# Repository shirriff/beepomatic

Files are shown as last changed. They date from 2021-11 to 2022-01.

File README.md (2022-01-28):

# beepomatic: automated backplane finding for Apollo-era hardware

This repository describes hardware and software for reverse-engineering a test box used with Apollo space hardware.
This is unlike to be useful to anyone else, but I figure I'll document it.

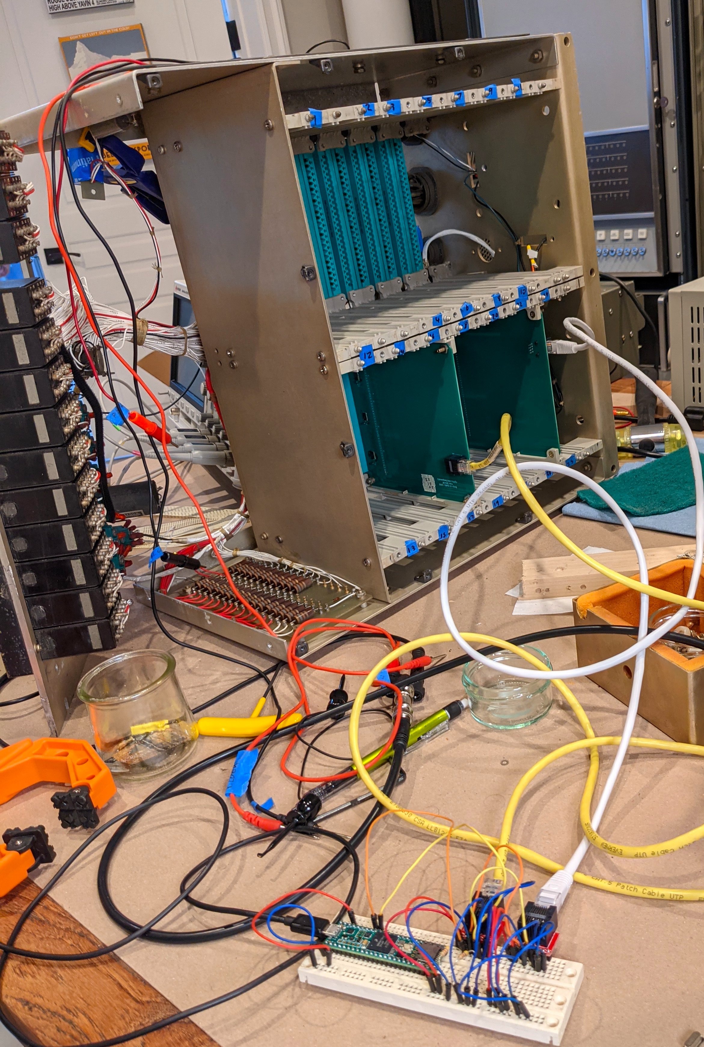
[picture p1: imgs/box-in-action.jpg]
The test system in action. Two boards are plugged into the box at the back and are controlled by the breadboarded Teensy in front.


## Background

In the Apollo mission to the Moon, the [Up-Data Link](https://mobile.twitter.com/kenshirriff/status/1433169432709373953) was used to send data up to the spacecraft from
the ground.

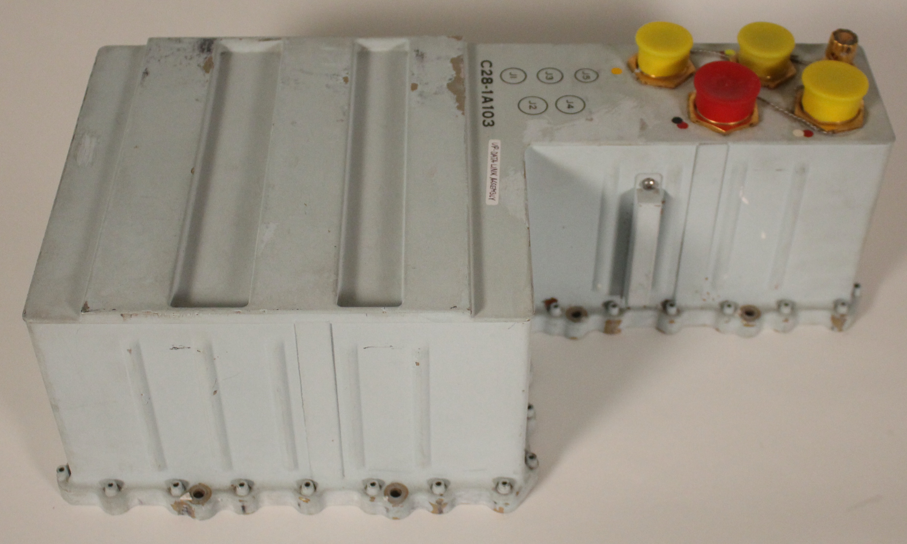
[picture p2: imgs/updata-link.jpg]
The Up-Data Link is a metal box painted a military gray. The box is roughly L-shaped and has several round connectors on top.


To test the Up-Data Link, the [Up-Data Link Confidence Test Set](https://twitter.com/kenshirriff/status/1432411774985195527) was used.
Unfortunately, we can't find any documentation on this test box, so I'm reverse-engineering it.

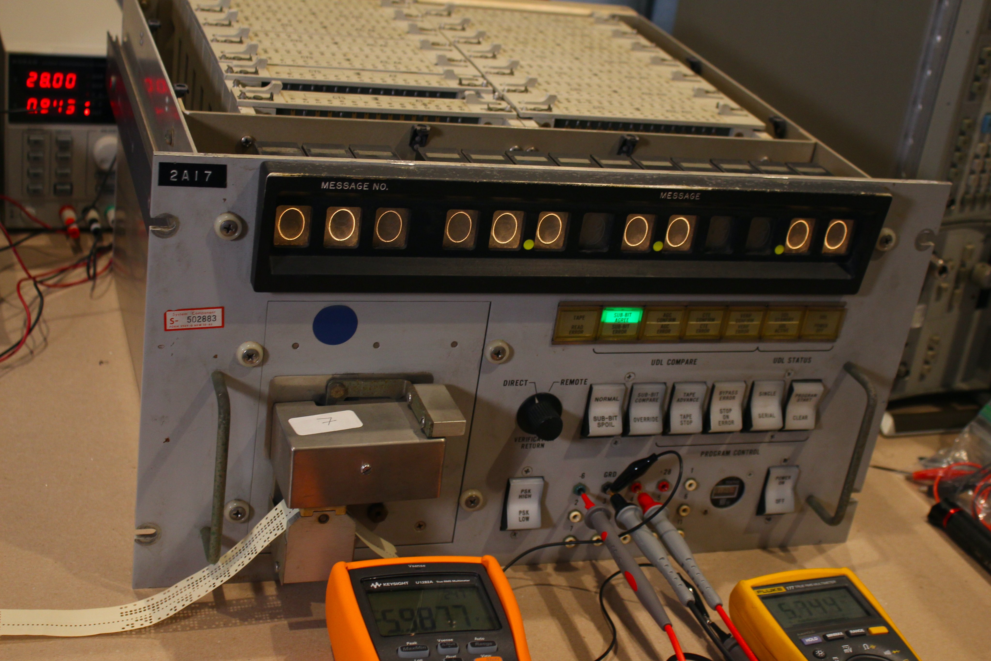
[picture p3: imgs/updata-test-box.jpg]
The up-data test box is a large rack-mountable box. It has a paper tape reader and switches, buttons, and illuminated digits on the front. 25 modules are plugged into the top of the box.


The box consists of 25 circuit boards plugged into a wire-wrapped backplane. It's almost impossible to figure out how the boards are connected through this
tangle of wires. I beeped out some connections with a multimeter, but it is extremely tedious to do this manually through trial and error.
So I decided to automate the beeping process.

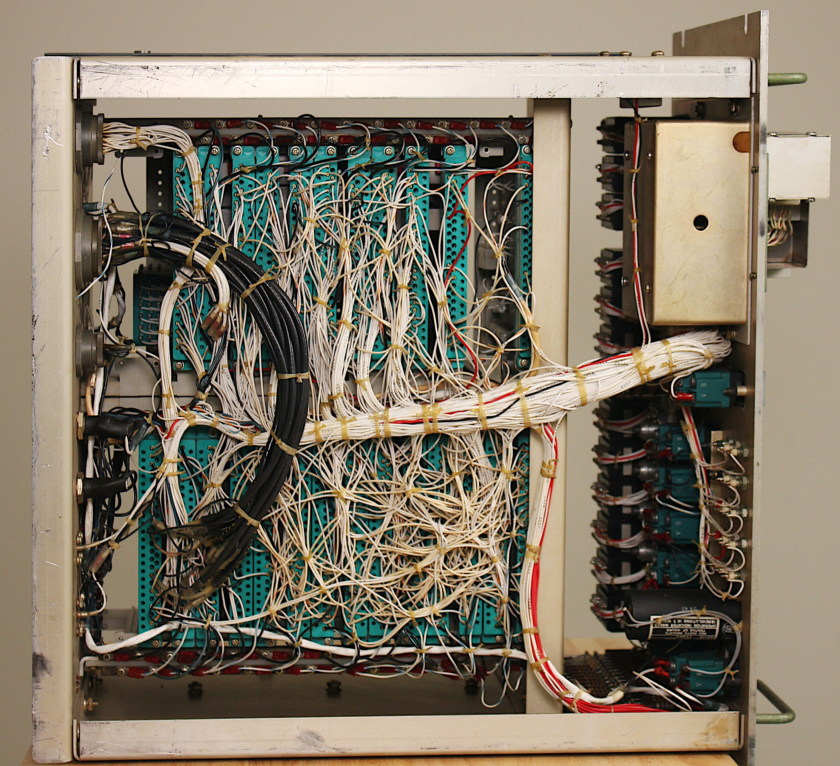
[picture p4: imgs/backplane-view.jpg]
View of the backplane, a tangled mass of white wires.


## Beep-o-matic

My idea was to build two boards that will automatically beep out the connections between them.
The idea is to pull one pin low and then see which other pins are pulled low on the other board; this indicates the pins are connected.

I still need to put boards into each combination of slots, so I need to run 300 scans. This is still somewhat tedious, but much better than probing the entire backplane
manually to find a single connection.

### Implementation

The backplane is implemented with 47-pin Elco connectors. Each board has three 16-bit GPIO chips connected to these pins; I used [PCA9555A](https://www.nxp.com/docs/en/data-sheet/PCA9555A.pdf) chips.)
The chips are driven over I2C from a Teensy microcontroller.
(Thanks to [PCBWay](https://www.pcbway.com/) for sponsoring these boards.)

On the software side, I wrote a simple program *beeper.ino*, which cycles through the 47 pins on each board, pulling each pin low in turn. It reads the remaining pins to see which ones are low
and outputs that data to the serial port. It takes under a second to perform this scan.

I run *beeper.py* on my laptop; it records the output for each scan in output files.

Finally, the program *net.py* processes these output files to find connected components and output the wiring nets.

### Issues

I pulled out all the boards, so I don't get any interference from the circuitry. However, the power and ground connections are still wired to the filter capacitors.
As a result, I see phantom connections between power and ground because of current flow through the capacitor. (This happens with multimeter beeping too.)
More inconvenient, though, is that once the capacitors are charged low, they can continue to pull the ground pins low even when I'm scanning unrelated pins.
This can make it appear that most pins are connected to ground. I filter this out in the software analysis.

A second problem is that the box has a lot of wiring to front panel switches, which are connected to power or ground (depending on their position).
I'll need to sort out that wiring manually.

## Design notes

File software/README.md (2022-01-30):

# Software for use with beepomatic

Disclaimer: these are ad hoc scripts that I used once, so don't expect them to be generally usefl.

The main programs:

* beeper.ino: This runs on the Teensy and drives the boards, scanning all pin pairs. It returns raw connectivity data over the serial port.

* beeper.py: Driver for beeper.ino. Run this on your laptop and it talks to the Teensy over the serial port. The workflow is that you plug the boards into two slots. Then enter the slot numbers into beeper.py. It will record the results in a file output-*n*, creating a new file each time you run it. So you end up with one or more output-*n* files with the data.

* net.py: Makes a net from the output-*n* files, determining the connected components. If a `labels.txt` file exists, it will label pins from that file.
Output to stdout, can be directed to out.txt.

Other programs:

* raw.ino: Runs on the Teensy to detect raw connections. Instead of scanning, this program just returns raw data. The idea is that you can probe pins manually and this program will let you know what the pin is connected to.

* changes.py: Driver program that uses audio to indicate any connectivity changes. If you're poking around in the box flipping switches and can't watch the screen, this program lets you know when something happens.

* fixlabels.py: The idea is to list all the unconnected pins in missing-pins.txt. This program then scans labels.txt and missing-pins.txt to make sure they are consistent, pins are either labeled or explicitly marked as missing.
This program generates labels-new.txt, the updated version.

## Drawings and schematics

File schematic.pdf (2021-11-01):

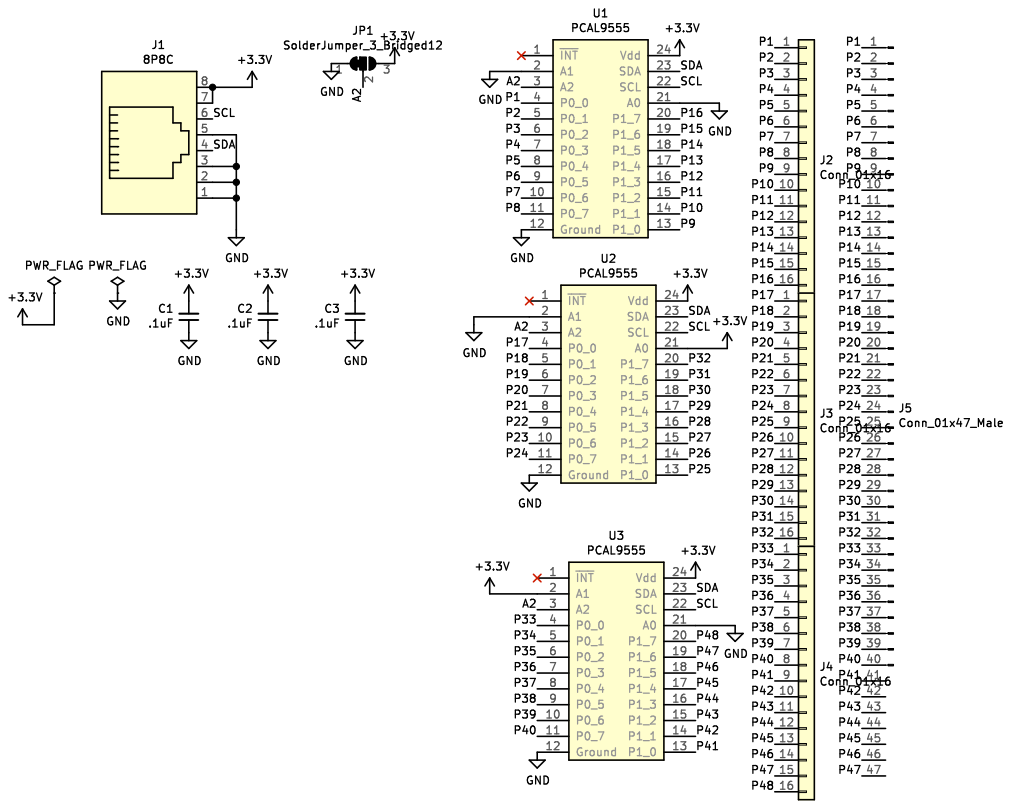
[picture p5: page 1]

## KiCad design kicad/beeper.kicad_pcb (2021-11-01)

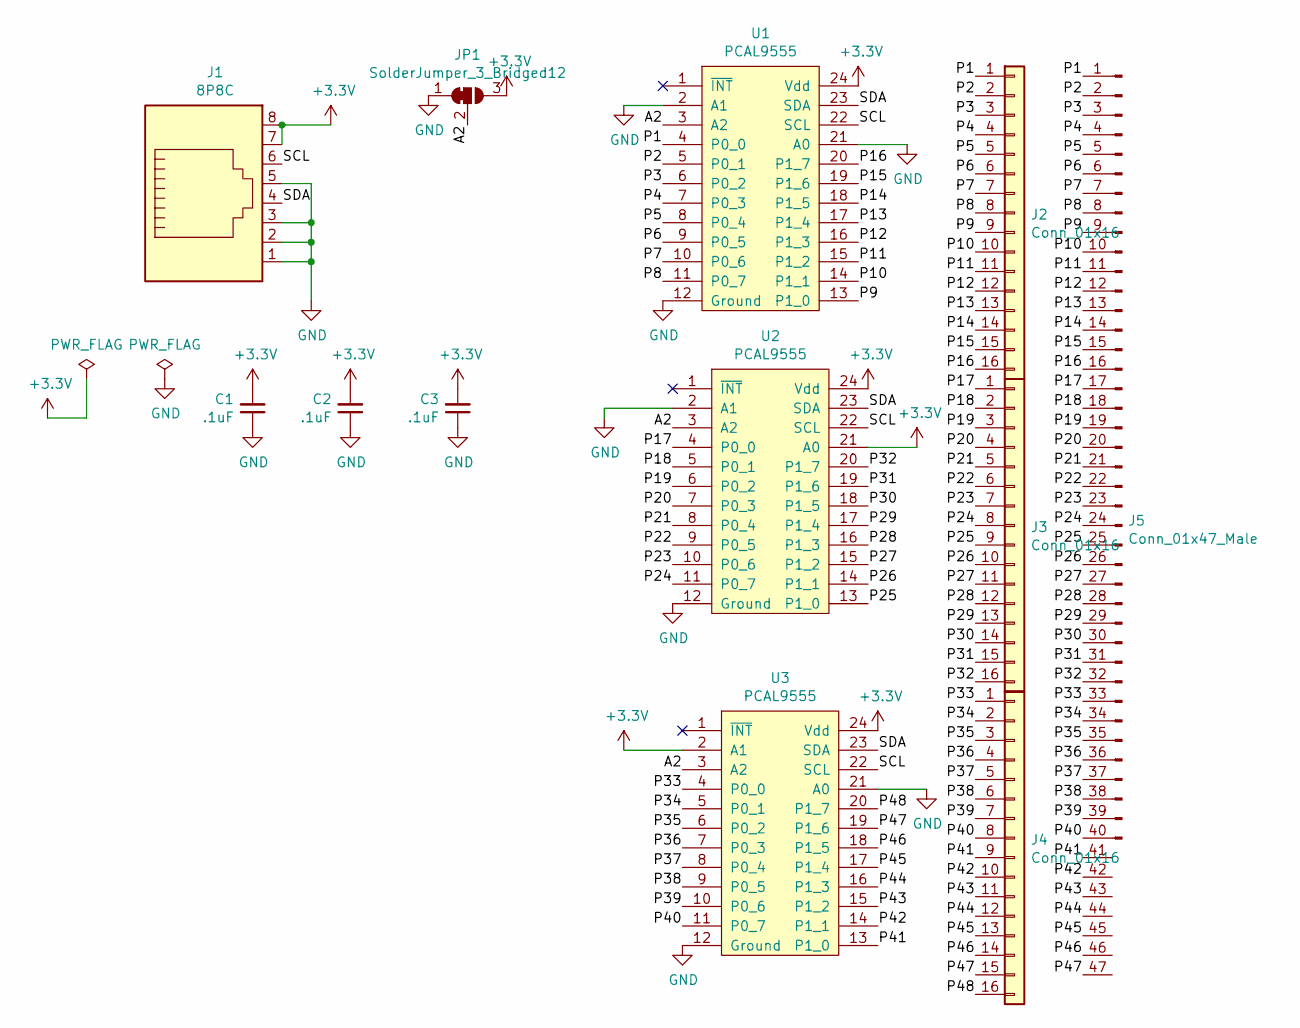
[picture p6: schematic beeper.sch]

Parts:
C1, C2, C3: .1uF; C_Disc_D3.0mm_W2.0mm_P2.50mm
J1: 8P8C; RJ45-8
J2, J3, J4: Conn_01x16; Pin_Header_Straight_1x16_Pitch2.54mm
J5: Conn_01x47_Male; elco-47
JP1: SolderJumper_3_Bridged12; SMT-JUMPER_3_NO_SILK
U1, U2, U3: PCAL9555; TSSOP-24_4.4x7.8mm_Pitch0.65mm

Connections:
+3V3: C1.2, C2.2, C3.2, J1.7, J1.8, JP1.3 (B), U1.24 (Vdd), U2.21 (A0), U2.24 (Vdd), U3.2 (A1), U3.24 (Vdd)
/A2: JP1.2 (C), U1.3 (A2), U2.3 (A2), U3.3 (A2)
/P1: J2.1, J5.1, U1.4 (P0_0)
/P2: J2.2, J5.2, U1.5 (P0_1)
/P3: J2.3, J5.3, U1.6 (P0_2)
/P4: J2.4, J5.4, U1.7 (P0_3)
/P5: J2.5, J5.5, U1.8 (P0_4)
/P6: J2.6, J5.6, U1.9 (P0_5)
/P7: J2.7, J5.7, U1.10 (P0_6)
/P8: J2.8, J5.8, U1.11 (P0_7)
/P9: J2.9, J5.9, U1.13 (P1_0)
/P10: J2.10, J5.10, U1.14 (P1_1)
/P11: J2.11, J5.11, U1.15 (P1_2)
/P12: J2.12, J5.12, U1.16 (P1_3)
/P13: J2.13, J5.13, U1.17 (P1_4)
/P14: J2.14, J5.14, U1.18 (P1_5)
/P15: J2.15, J5.15, U1.19 (P1_6)
/P16: J2.16, J5.16, U1.20 (P1_7)
/P17: J3.1, J5.17, U2.4 (P0_0)
/P18: J3.2, J5.18, U2.5 (P0_1)
/P19: J3.3, J5.19, U2.6 (P0_2)
/P20: J3.4, J5.20, U2.7 (P0_3)
/P21: J3.5, J5.21, U2.8 (P0_4)
/P22: J3.6, J5.22, U2.9 (P0_5)
/P23: J3.7, J5.23, U2.10 (P0_6)
/P24: J3.8, J5.24, U2.11 (P0_7)
/P25: J3.9, J5.25, U2.13 (P1_0)
/P26: J3.10, J5.26, U2.14 (P1_1)
/P27: J3.11, J5.27, U2.15 (P1_2)
/P28: J3.12, J5.28, U2.16 (P1_3)
/P29: J3.13, J5.29, U2.17 (P1_4)
/P30: J3.14, J5.30, U2.18 (P1_5)
/P31: J3.15, J5.31, U2.19 (P1_6)
/P32: J3.16, J5.32, U2.20 (P1_7)
/P33: J4.1, J5.33, U3.4 (P0_0)
/P34: J4.2, J5.34, U3.5 (P0_1)
/P35: J4.3, J5.35, U3.6 (P0_2)
/P36: J4.4, J5.36, U3.7 (P0_3)
/P37: J4.5, J5.37, U3.8 (P0_4)
/P38: J4.6, J5.38, U3.9 (P0_5)
/P39: J4.7, J5.39, U3.10 (P0_6)
/P40: J4.8, J5.40, U3.11 (P0_7)
/P41: J4.9, J5.41, U3.13 (P1_0)
/P42: J4.10, J5.42, U3.14 (P1_1)
/P43: J4.11, J5.43, U3.15 (P1_2)
/P44: J4.12, J5.44, U3.16 (P1_3)
/P45: J4.13, J5.45, U3.17 (P1_4)
/P46: J4.14, J5.46, U3.18 (P1_5)
/P47: J4.15, J5.47, U3.19 (P1_6)
/P48: J4.16, U3.20 (P1_7)
/SCL: J1.6, U1.22 (SCL), U2.22 (SCL), U3.22 (SCL)
/SDA: J1.4, U1.23 (SDA), U2.23 (SDA), U3.23 (SDA)
GND: C1.1, C2.1, C3.1, J1.1, J1.2, J1.3, J1.5, JP1.1 (A), U1.2 (A1), U1.12 (Ground), U1.21 (A0), U2.2 (A1), U2.12 (Ground), U3.12 (Ground), U3.21 (A0)

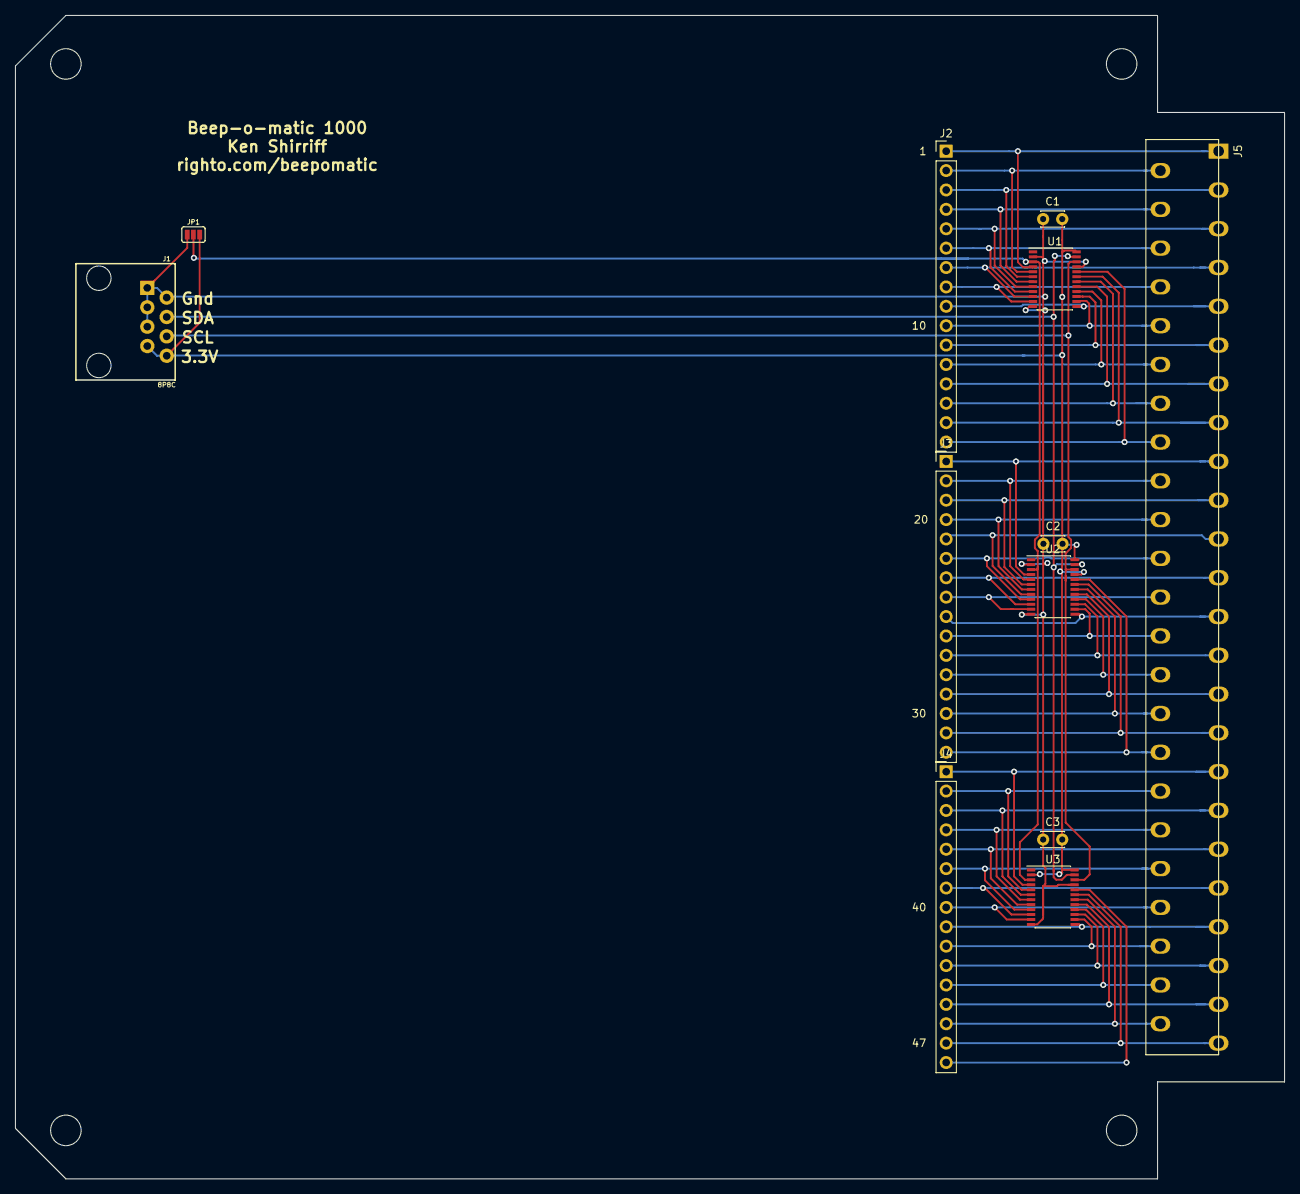
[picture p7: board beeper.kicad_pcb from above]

Board: 2 copper layers, 166.2 x 152.4 mm, 12 parts (0 on the bottom side), 53 nets.

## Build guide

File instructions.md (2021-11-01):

## Teensy 4.1 wiring

I did the Teensy wiring on a solderless breadboard because it was too simple to be worth a PCB.
I use Ethernet cables to connect the boards to the Teensy; the signal is I2C not Ethernet, but this was a convenient cable.

Wire two Ethernet jacks ([breakout](https://www.sparkfun.com/products/716)) in parallel:\
Ground to jack pins 1, 2, 3, 5.\
Teensy pin 18 (SDA) and a 4.7K pullup resistor to jack pin 4.\
Teensy pin 19 (SCL) and a 4.7K pullup resistor to jack pin 6.\
+3.3V to jack pins 7 and 8.

## Collecting the data
Connect the cables to the Teensy and the Teensy to the laptop. Run *beeper.py*.\
Put the boards in box slots 1 and 2. (The boards are distinguished by the solder jumpers on them.)\
Enter "1 2" into the laptop and it will find the connections (via Teensy serial) and log them in the output file.\
Move the second board to slot 3 and enter "1 3". Move the board to slot 4, etc.
Note that the board needs to be inverted for many slots.
Once the second board has been in all the slots, move the boards to slots 2 and 3 and repeat.\
*beeper.py* can be restarted; it will create a new output file each time, preserving the old files.

## Processing the data
Run *net.py* and it will generate the nets from the output files.

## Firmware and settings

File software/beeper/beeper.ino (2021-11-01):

// The main driver program for the beeper boards.
// There are two boards: one has pins 1-48 and the second has pins 101-148.
// The idea is to pull each pin low in sequence. After pulling a pin low,
// check all the other pins to see if they have been pulled low, indicating
// a backplane connection between them.
//
// Each board has three PCAL955A chips, each providing 16 I/O lines.
// The chips are controlled over I2C.
//
// Each time a character is received on the serial input, a scan is performed.

// https://righto.com/beepomatic

#include <Wire.h>

const byte addrs[6] = {0x20, 0x21, 0x22, 0x24, 0x25, 0x26};
#define IN_PORT 0x00
#define OUT_PORT 0x02
#define CONFIG 0x06

bool error = false;

// I2C primitives

void writeByte(int chip, int port, byte value) {
  Wire.beginTransmission(addrs[chip]);
  Wire.write(port);
  Wire.write(value);
  error = Wire.endTransmission();
  if (error) {
    Serial.print("Error: ");
    Serial.println(error, HEX);
  }
}

byte readByte(int chip, int port) {
  Wire.beginTransmission(addrs[chip]);
  Wire.write(port);
  error = Wire.endTransmission();
  if (error) {
    Serial.print("Read error: ");
    Serial.println(error, HEX);
    return 0;
  }

  Wire.requestFrom(addrs[chip], 1);
  return Wire.read();
}

// Internally, pins are 0-47 and 48-95. Note: 47 and 95 are not used.
// Externally, want to display 1-48 and 101-148.
int pinName(int pin) {
  if (pin > 47) {
    return 101 + pin - 48;
  } else {
    return pin + 1;
  }
}

// Read all the inputs to find any connections
void findConnections(int src) {
  bool found = false;
  for (int chip = 0; chip < 6; chip++) {
    for (int bank = 0; bank < 2; bank++) {
      byte value = readByte(chip, IN_PORT + bank);
      if (error) return;
      for (int bit = 0; bit < 8; bit++) {
        int dst = pinName(chip * 16 + bank * 8 + bit);
        if (src == dst) continue;

        if ((value & (1 << bit)) == 0) {
          if (!found) {
            Serial.print(src, DEC); // Use first pin #1 for output
            Serial.print(":");
            found = true;
          }
          Serial.print(" ");
          Serial.print(dst, DEC); // Start with #1
        }
      }
    }
  }
  if (found) {
    Serial.println("");
  }
}

// The main loop to scan over all the pins
void scan() {
  for (int board = 0; board < 2; board++) {
    for (int count = 0; count < 48; count++) {
      int chip = 3 * board + (count >> 4);
      int bank = (count >> 3) & 1;
      int bit = count & 7;
      writeByte(chip, CONFIG + bank, 0xff ^ (1 << bit)); // Set one line as output
      if (error) return;
      findConnections(pinName(48 * board + count));
      writeByte(chip, CONFIG + bank, 0xff);
      if (error) return;
    }
  }
}

void setup() {
  Wire.begin();
  Serial.begin(9600);
  Serial.println(F("\nbeeper"));

  for (int chip = 0; chip < 6; chip++) {
    for (int bank = 0; bank < 2; bank++) {
      writeByte(chip, CONFIG + bank, 0xff); // Set all lines as input
      writeByte(chip, OUT_PORT + bank, 0x00); // Set output bits all low
    }
  }
  Serial.println("Initialized");
}

void loop() {
  int ch = Serial.read();
  if (ch == 'g') { // g for go full speed
    while (1) {
      scan(); 
      if (Serial.read() == '1') break; // Stop on '1'
    }
  } else if (ch >= 0) { // Do one scan
    error = false; // Reset any errors
    Serial.println("start");
    scan();
    Serial.println("end");
    while (Serial.read() != -1) {} // Discard extra characters
  }
}

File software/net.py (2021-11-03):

# Make a net from the connection files output-*

# Uses networkX: "pip install networkx"

import glob
import re
import sys

import networkx as nx

from collections import defaultdict

G = nx.Graph() # The graph of connections

boardGrounds = set() # All the grounds


# Some statistics
counts = defaultdict(lambda: 0)
pairs = defaultdict(lambda: set()) # Keep track of which boards we process
scans = 0 # Keep track of how many scans we process
wires = 0

# pins 1-47 are on the first board, 101-147 are on the second board.
# Returns a string e.g. 1p3 for pin 3 on board 1.
def pinName(slots, num):
  if num < 100:
    return '%dp%d' % (slots[0], num)
  else:
    return '%dp%d' % (slots[1], num - 100)

grounds = set()

# Process a single line from the output file
def processLine(slots, line):
  global G, grounds
  m = re.match('(\d+): (.*)', line)
  if not m:
    sys.exit('bad data %s' % line)
  parts = tuple(map(int, m.group(2).split(' ')))
  pin1 = int(m.group(1))
  if pin1 == 1:
    grounds = set(parts) # Filter out everything connected to pin 1 as a power/ground connection
    grounds.add(1)
  name1 = pinName(slots, pin1)
  for pin2 in parts:
    name2 = pinName(slots, pin2)
    if pin2 in grounds:
      # Skip the ground connection
      boardGrounds.add(name2)
      continue
    G.add_edge(name1, name2)
    counts[pin1] += 1
    counts[pin2] += 1
    global wires
    wires += 1

# Process the wiring information from one output file
# Format is e.g.
# 8: 9 101
# indicating pin 8 is connected to pins 9 and 101 (i.e. pin 9 on board 1 and pin 1 on board 2).
def readFile(f):
  state = 'begin'
  for line in f.readlines():
    line = line.strip()
    if state == 'begin':
      m = re.match('slots: (\d+) (\d+)', line)
      global scans, grounds
      scans += 1
      grounds = set() # Clear the set of ground connections
      if m:
        slots = (int(m.group(1)), int(m.group(2)))
        pairs[slots[0]].add(slots[1])
        state = 'start'
      else:
        sys.exit('unexpected %s' % line)
    elif state == 'start':
      if line == 'start':
        state = 'data'
      else:
        sys.exit('expected start, got %s' % line)
    elif state == 'data':
      if line == 'end':
        state = 'begin'
      else:
        processLine(slots, line)

def filter(component):
  return True
  for c in component:
    if c.startswith('1p'): return True
  return False

# Sort key function for pins
# This converts "12p34" to [outFlag, 12, 34] so they will sort numerically
# The outFlag puts pins labeled 'out' at the front as they are more important
def pinSort(x):
  board, pin = map(int, x.split('p'))
  if 'out' in labels.get(x, ''):
    return [0, board, pin]
  else:
    return [1, board, pin]

def results():
  global G
  components = nx.connected_components(G)
  pinToNet = {}
  for c in components:
    for pin in c:
      pinToNet[pin] = c

  # Attach a label (if any) to the pin
  def label(p):
    if p in labels:
      return '%s(%s)' % (p, labels[p])
    else:
      return p

  # Truncate a list that's too long
  def trunc(t):
    if len(t) > 5:
      t.sort(key=pinSort)
      return '%s...' % t[0:3]
    else:
      return t

  for board in range(1, 26):
    print('\n--- board %d: %s' % (board, boards[board]))
    for pin in range(4, 48): # Skip pins 1-3
      pinName = '%dp%d' % (board, pin)
      if pinName in pinToNet:
        pins = sorted(pinToNet[pinName], key=pinSort)
        if len(pins) > 4:
          print(label(pinName) + ':', ', '.join([label(p) for p in pins[0:4] if p != pinName]), '...')
        else:
          print(label(pinName) + ':', ', '.join([label(p) for p in pins if p != pinName]))
      elif pinName in boardGrounds:
        if 'emitter' in label(pinName):
          print(label(pinName))
        else:
          print(label(pinName) + ': ground (switch?)')
      elif pinName in labels:
        print(label(pinName) + ': n/c?')

  print('--- grounds (switches) ---')
  for board in range(1, 26):
    header = '--- board %d' % board
    for pin in range(4, 48): # Skip pins 1-3
      pinName = '%dp%d' % (board, pin)
      if pinName in boardGrounds:
        if header:
          print(header)
          header = None
        print(label(pinName))

  if False:
    print('\n--- todo ---')
    todoCount = 0
    for board1 in range(1, 25):
      todo = [b for b in range(board1 + 1, 26) if b not in pairs[board1]]
      todoCount += len(todo)
      if todo:
        print(board1, todo)
      else:
        print(board1, 'done!')
    print('To do:', todoCount)

labels = {}
boards = {} # From board number to board description
def readLabels():
  try:
    with open('labels.txt') as f:
      for line in f.readlines():
        line = line.strip()
        if not line: continue
        m = re.match('#(\d+) (.*)', line)
        if m:
          boards[int(m.group(1))] = m.group(2)
          continue
        try:
          pin, label = line.split(' ', 1)
        except ValueError:
          sys.exit('Bad line %s' % line)
        if pin in labels:
          print('Dup label', pin, labels[pin], label)
        labels[pin] = label
  except FileNotFoundError:
    print('no label file')

def main():
  readLabels()
  for fname in glob.glob('output-*'):
    with open(fname) as f:
      readFile(f)
  results()

if __name__ == "__main__":
    main()

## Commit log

2021-11-01 Initial checkin
    Initial checkin of the hardware and software
    [beeper.kicad_pcb, beeper.sch]
2022-01-28 Put a time delay so the program won't talk too much.
    [changes.py]
2022-01-28 Add fixlabels to check consistency
    [fixlabels.py]
2022-01-30 Fix off-by-one error in pin ranges. Clean up input so fixlabels can be run multiple times.
    [fixlabels.py]
